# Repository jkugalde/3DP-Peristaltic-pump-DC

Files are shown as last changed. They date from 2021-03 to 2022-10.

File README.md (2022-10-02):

# Summary

My take on making a small peristaltic pump, using 3d printed parts and a DC motor. It has been tested successfully with glycerine, and controlled in an open and closed loop system, which are included in this repository.

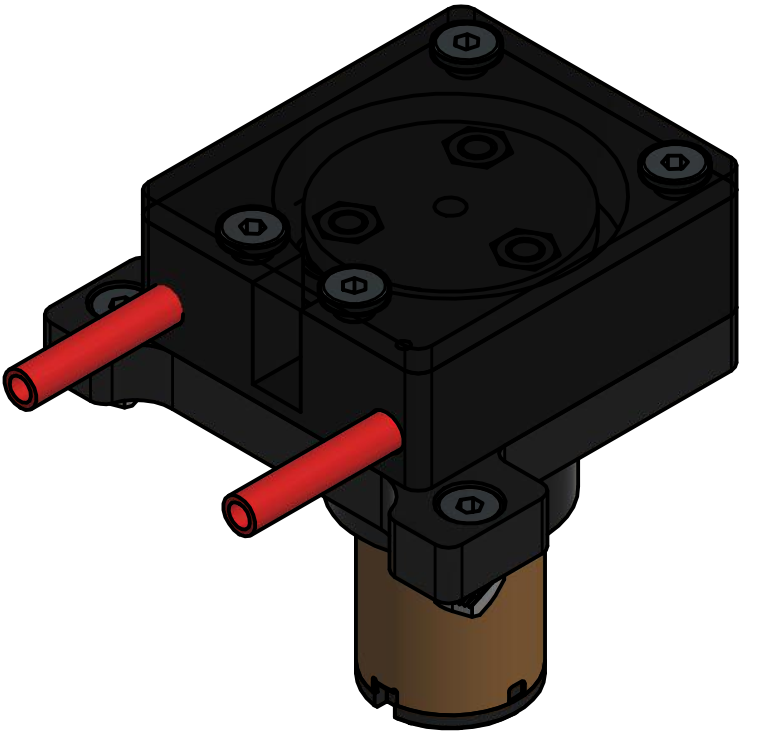
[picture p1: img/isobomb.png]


The assembly instructions are [HERE](https://jkugalde.github.io/portfolio/ppdc/).
The parts are [HERE](https://grabcad.com/library/3dp-peristaltic-pump-2).

## License

This work is published under the license [Creative Commons Attribution 4.0 International
License][cc-by-sa].

[][cc-by-sa]

[cc-by-sa]: https://creativecommons.org/licenses/by-sa/4.0/
[cc-by-sa-image]: https://i.creativecommons.org/l/by-sa/4.0/88x31.png

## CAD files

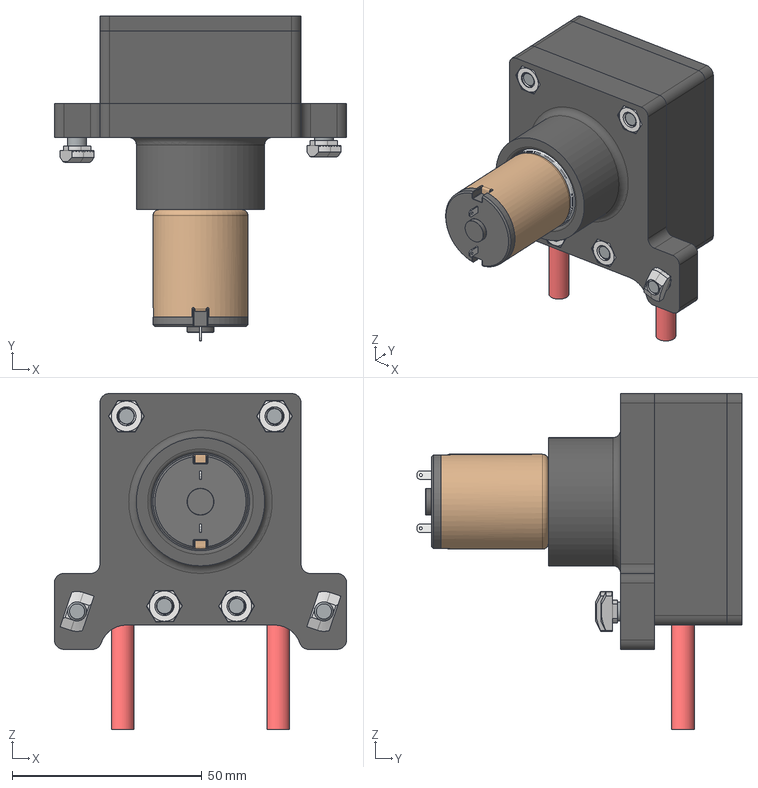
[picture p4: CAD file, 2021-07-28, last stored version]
parts/BombaPeristaltica.stp
77.0 x 85.6 x 88.5 mm
JGA25-372 24V Motor
Impulsor_1
W 605-2Z_PART1 x 6
W 605-2Z_PART2 x 6
W 605-2Z_PART3 x 42
W 605-2Z_PART4 x 42
PrisioneroM3 x 3
M3Nut x 3
M5Nut x 3
Perno M5x15 cabeza plana_ x 3
Caja2
TapaSuperior
M3x6SinkBolt x 2
CASEB_v3
GolillaM4
Manguera
Perno M5x8 cabeza plana x 4
M5Nut_1 x 4
T_Slot_Nut_Dropin_2020 m5 v2 x 2
Perno M5x8 cabeza plana_1 x 2

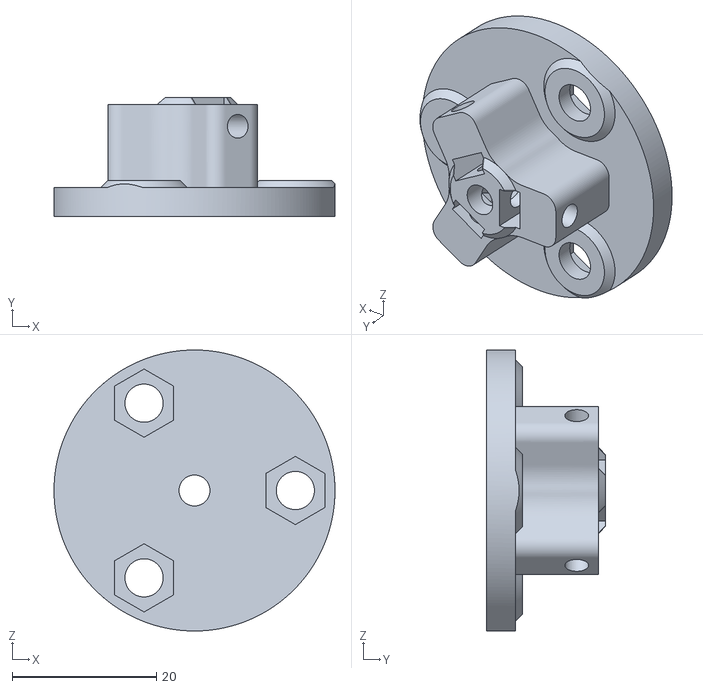
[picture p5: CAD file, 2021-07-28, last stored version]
parts/STLs/Impulsor.stl
39.0 x 16.5 x 39.0

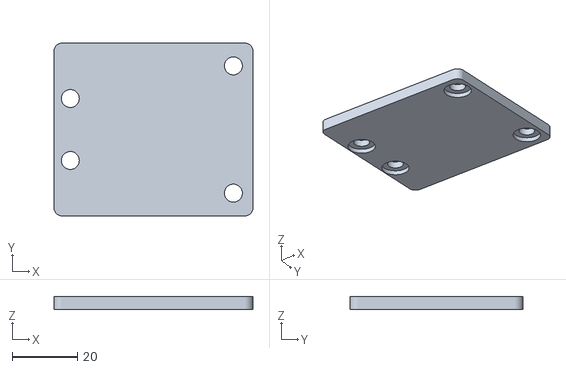
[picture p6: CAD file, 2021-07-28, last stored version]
parts/STLs/TapaSuperior.stl
61.0 x 53.0 x 4.00

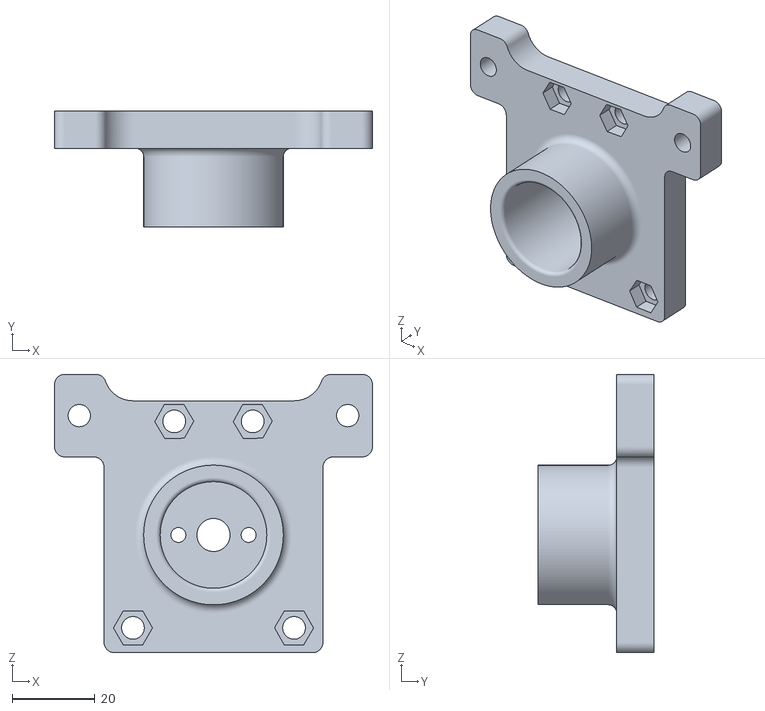
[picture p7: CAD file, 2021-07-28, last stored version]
parts/STLs/TapaInferior.stl
77.0 x 28.0 x 67.4

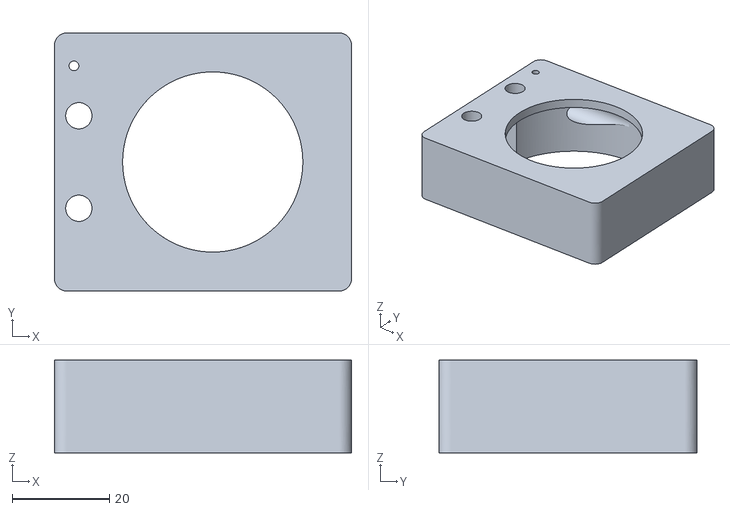
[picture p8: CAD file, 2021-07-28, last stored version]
parts/STLs/CajaBomba.stl
61.0 x 53.0 x 19.0

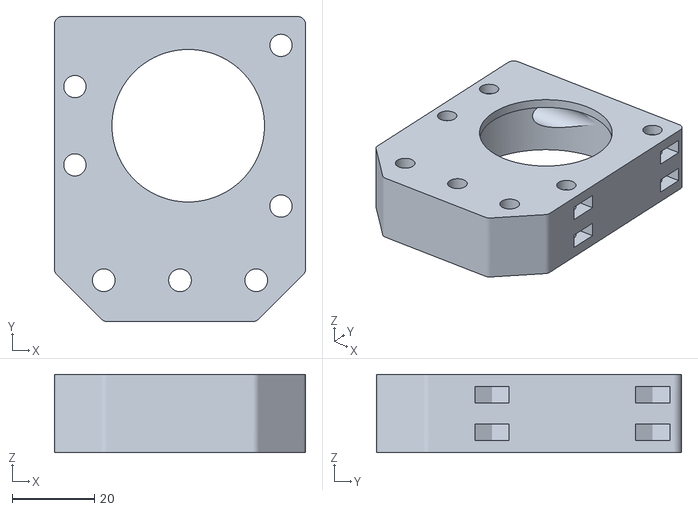
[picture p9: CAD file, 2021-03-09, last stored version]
parts/STLs/Caja.stl
61.0 x 74.0 x 19.0

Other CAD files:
parts/Inventor parts/OldVersions/PlanoBomba.0001.dwg
parts/Inventor parts/605ZZ/OldVersions/Rodamiento605ZZ.0001.iam
parts/Inventor parts/605ZZ/OldVersions/Rodamiento605ZZ.0004.iam
parts/Inventor parts/605ZZ/OldVersions/W 605-2Z_PART1.0001.ipt
parts/Inventor parts/605ZZ/OldVersions/W 605-2Z_PART2.0001.ipt
parts/Inventor parts/605ZZ/OldVersions/W 605-2Z_PART3.0001.ipt
parts/Inventor parts/605ZZ/OldVersions/W 605-2Z_PART4.0001.ipt
parts/Inventor parts/605ZZ/Rodamiento605ZZ.iam
parts/Inventor parts/605ZZ/W 605-2Z_PART1.ipt
parts/Inventor parts/605ZZ/W 605-2Z_PART2.ipt
parts/Inventor parts/605ZZ/W 605-2Z_PART3.ipt
parts/Inventor parts/605ZZ/W 605-2Z_PART4.ipt
parts/Inventor parts/BombaPeristaltica.iam
parts/Inventor parts/Caja.ipt
parts/Inventor parts/CajaBomba.ipt
parts/Inventor parts/GolillaM4DIN125.ipt
parts/Inventor parts/GolillaM5DIN125.ipt
parts/Inventor parts/Impulsor.iam
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

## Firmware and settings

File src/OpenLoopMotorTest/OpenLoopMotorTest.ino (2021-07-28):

// Utilizando el monitor serial, introduce un número entre -255 y 255 para que el motor gire, 0 para que se detenga.


#define DC_IN1 2
#define DC_IN2 4
#define DC_PWM 3

int pwm = 0;

void setup() {

  Serial.begin(9600);
  pinMode(DC_IN1,OUTPUT);
  pinMode(DC_IN2,OUTPUT);
  pinMode(DC_PWM,OUTPUT);
  
}

void loop() {
  
  if(Serial.available()>0){
      pwm=Serial.parseInt();
  }
  if(pwm>0){
    pwm=constrain(pwm,0,255);
    digitalWrite(DC_IN1,HIGH);
    digitalWrite(DC_IN2,LOW);    
  }
  if(pwm<0){
    pwm=constrain(pwm,-255,0);
    digitalWrite(DC_IN1,LOW);
    digitalWrite(DC_IN2,HIGH);    
  }
  if(pwm==0){
    digitalWrite(DC_IN1,LOW);
    digitalWrite(DC_IN2,LOW);
  }
    analogWrite(DC_PWM,pwm);
}

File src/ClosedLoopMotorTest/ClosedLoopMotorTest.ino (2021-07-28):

// utiliza el monitor serial para ingresar la cantidad de gramos de material a dispensar.
// debes configurar la celda antes de ocupar el sistema
// la constante proporcional del controlador también debe ser calibrada

#include "HX711.h"

#define DC_IN1 2
#define DC_IN2 4
#define DC_PWM 3

int pwm = 0;
float target = 0;
float masa = 0;
boolean dispensing = false;

#define Kp 100

#define CC_CLK 5
#define CC_DAT 6
#define calibrationfactor 965500 // celda de 1 kg

HX711 celda(CC_CLK,CC_DAT);

unsigned long sampletime = 50;

void setup() {

  Serial.begin(9600);
  celda.set_scale();
  celda.tare();
  celda.read_average();
  celda.set_scale(calibrationfactor);
  celda.tare();
  pinMode(DC_IN1,OUTPUT);
  pinMode(DC_IN2,OUTPUT);
  pinMode(DC_PWM,OUTPUT);
  Serial.println("gramos? ");
  
}

void loop() {
  
  if(Serial.available()>0 && dispensing==false){
      target=Serial.parseInt()*1.26;
      Serial.println(target);
      dispensing=true;
      celda.tare();
      delay(500);
  }

  if (dispensing==true){

  masa=celda.get_units()*1000;
  Serial.print(masa);
  Serial.print("      ");
  float error = target-masa;
  pwm=int(Kp*error);
  pwm=constrain(pwm,125,255);
  Serial.print(error);
  Serial.print("      ");
  Serial.println(pwm);

  if(masa>=target){
    dispensing=false;
    pwm=0;
    Serial.println(masa);
  }

  }
  
  digitalWrite(DC_IN1,HIGH);
  digitalWrite(DC_IN2,LOW);
  analogWrite(DC_PWM,pwm);
}

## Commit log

2021-03-09 almost all
    [BombaPeristaltica.0019.iam, BombaPeristaltica.iam, BombaPeristaltica.stp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]
2021-03-10 almost complete
    [BombaPeristaltica.0026.iam, BombaPeristaltica.iam, BombaPeristaltica.stp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]
2022-09-18 deleted parts in this repository, added external part repository
    [BombaPeristaltica.iam, BombaPeristaltica.stp, CajaBomba.ipt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]
